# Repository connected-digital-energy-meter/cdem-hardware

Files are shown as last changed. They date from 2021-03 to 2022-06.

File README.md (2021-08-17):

# Connected Digital Energy Meter - Hardware

TODO

## Gerber and BOM

Checkout following guides:

* [How to generate Gerber and Drill files in KiCad 5](https://support.jlcpcb.com/article/149-how-to-generate-gerber-and-drill-files-in-kicad)
* [How to generate the BOM and Centroid file from KiCAD](https://support.jlcpcb.com/article/84-how-to-generate-the-bom-and-centroid-file-from-kicad)

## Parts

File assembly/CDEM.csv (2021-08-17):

Comment | Designator | Footprint | LCSC
10uF | C1,C2,C3,C6 | Capacitor_SMD:C_0805_2012Metric | C15850
100nF | C4,C7,C8 | Capacitor_SMD:C_0603_1608Metric | C14663
1uF | C5 | Capacitor_SMD:C_0603_1608Metric | C15849
4.7uF | C9 | Capacitor_SMD:C_0805_2012Metric | C1779
1N5817 | D1,D2 | Diode_SMD:D_SOD-123 | C727113
power | D3 | LED_SMD:LED_0603_1608Metric | C72041
COMM | D4 | LED_SMD:LED_0603_1608Metric | C72043
DATA | D5 | LED_SMD:LED_0603_1608Metric | C72038
USB_C_Receptacle_USB2.0 | J1 | Connector_USB:USB_C_Receptacle_HRO_TYPE-C-31-M-12 | C165948
6P6C | J2 | Connector_RJ:RJ12_Amphenol_54601 | C305981
Conn_01x03 | J4 | Connector_PinHeader_2.54mm:PinHeader_1x03_P2.54mm_Vertical | C390679
2N7002 | Q1 | Package_TO_SOT_SMD:SOT-23 | C8545
S8050 | Q2,Q3 | Package_TO_SOT_SMD:SOT-23 | C2146
10k | R1,R2,R3,R6,R8,R9,R10,R11,R12 | Resistor_SMD:R_0603_1608Metric | C25804
1M | R13 | Resistor_SMD:R_0603_1608Metric | C17514
1k | R4,R5,R7 | Resistor_SMD:R_0603_1608Metric | C21190
BTN | SW1 | Button_Switch_SMD:SW_SPST_B3U-1000P | C231329
RESET | SW2 | Button_Switch_SMD:SW_SPST_B3U-1000P | C231329
MCP1825S | U1 | Package_TO_SOT_SMD:SOT-223-3_TabPin2 | C145411
USBLC6-2SC6 | U2 | Package_TO_SOT_SMD:SOT-23-6 | C7519
CP2104 | U3 | Package_DFN_QFN:QFN-24-1EP_4x4mm_P0.5mm_EP2.6x2.6mm | C47742
ESP-12E | U4 | RF_Module:ESP-12E | C82898

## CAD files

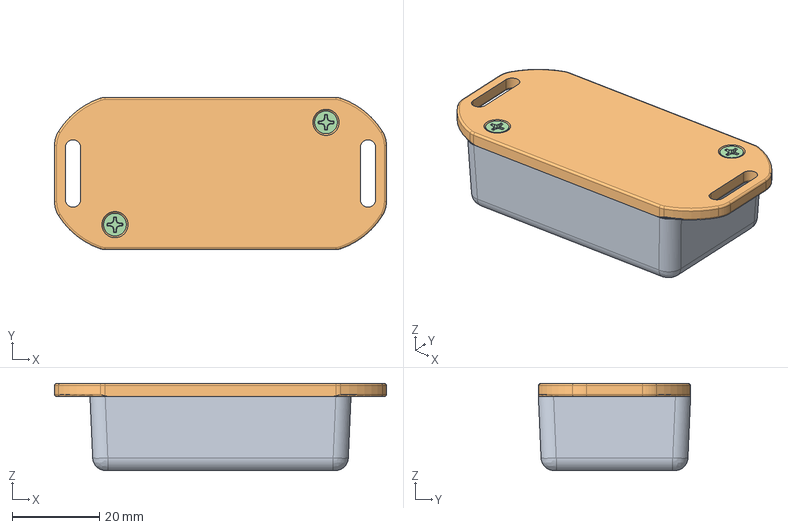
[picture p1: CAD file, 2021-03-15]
3Dmodels/1551HFL.stp
76.3 x 35.0 x 20.0 mm
1551H Box
1551H-J Flange Lid
1551H PCB

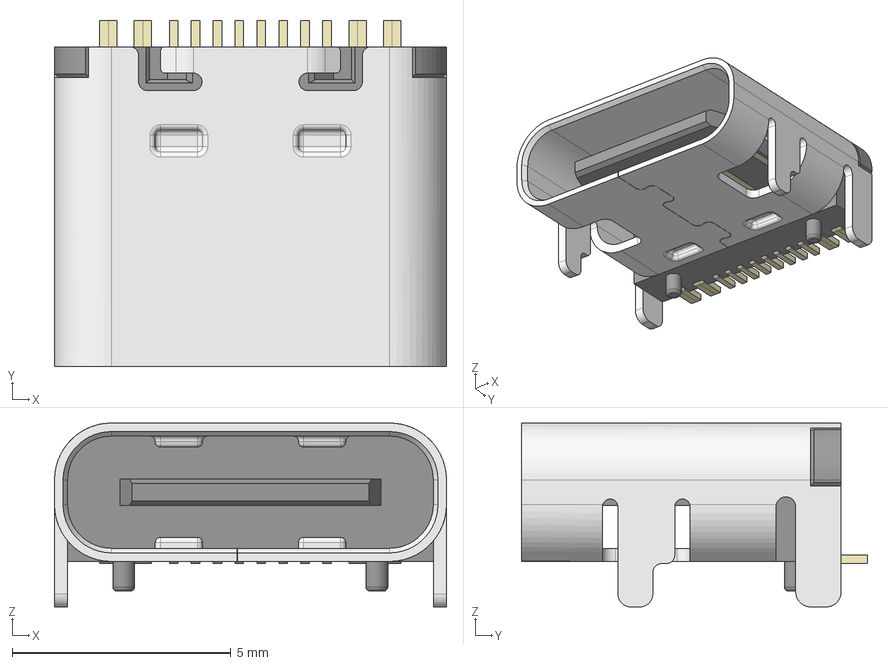
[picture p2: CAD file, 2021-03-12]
3Dmodels/HRO_TYPE-C-31-M-12.step
8.95 x 7.90 x 4.20 mm

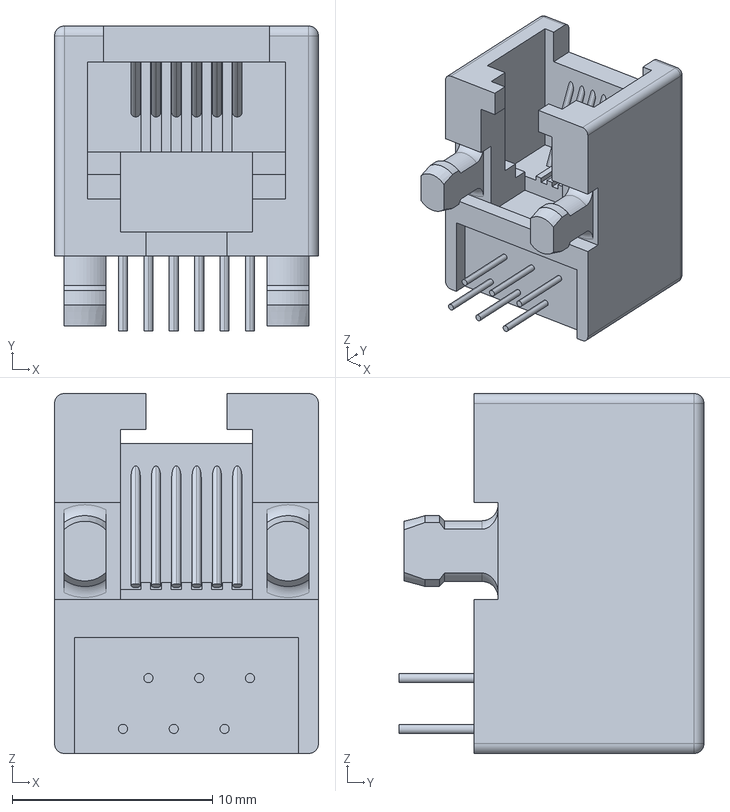
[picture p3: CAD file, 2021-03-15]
3Dmodels/54601-906WPLFc.stp
13.2 x 15.2 x 18.0 mm

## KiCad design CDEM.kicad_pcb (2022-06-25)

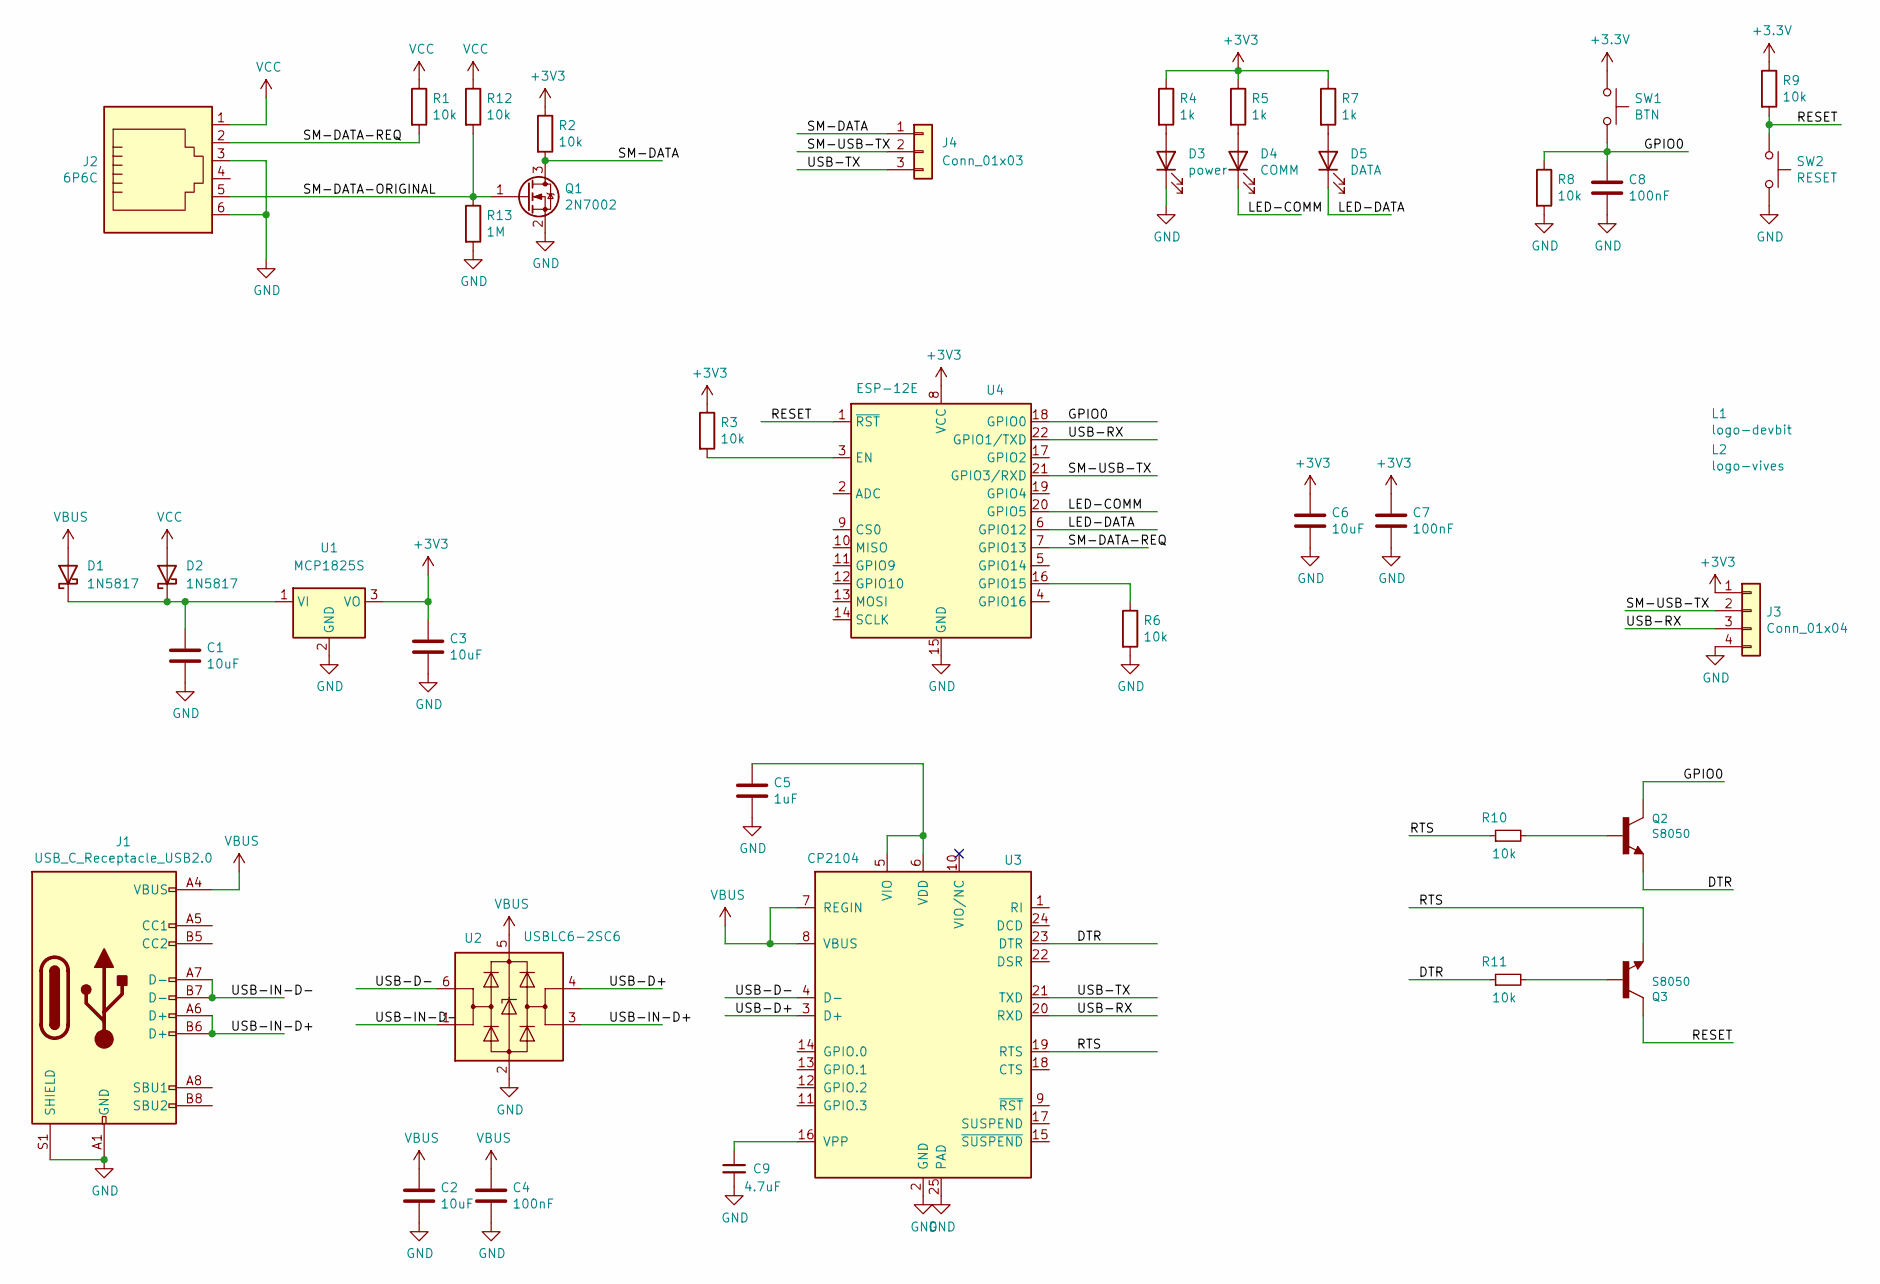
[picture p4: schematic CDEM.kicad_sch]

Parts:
C1, C2, C3, C6: 10uF; C_0805_2012Metric; LCSC C15850
C4, C7, C8: 100nF; C_0603_1608Metric; LCSC C14663
C5: 1uF; C_0603_1608Metric; LCSC C15849
C9: 4.7uF; C_0805_2012Metric; LCSC C1779
D1, D2: 1N5817; D_SOD-123; LCSC C727113
D3: power; LED_0603_1608Metric; LCSC C72041
D4: COMM; LED_0603_1608Metric; LCSC C72043
D5: DATA; LED_0603_1608Metric; LCSC C72038
J1: USB_C_Receptacle_USB2.0; USB_C_Receptacle_HRO_TYPE-C-31-M-12; LCSC C165948
J2: 6P6C; RJ12_Amphenol_54601; LCSC C305981
J3: Conn_01x04; PinHeader_1x04_P2.54mm_Vertical
J4: Conn_01x03; PinHeader_1x03_P2.54mm_Vertical; LCSC C390679
L1: logo-devbit; logo_devbit_8mm
L2: logo-vives; logo_vives_10mm
Q1: 2N7002; SOT-23; LCSC C8545
Q2, Q3: S8050; SOT-23; LCSC C2146
R1, R2, R3, R6, R8, R9, R10, R11, R12: 10k; R_0603_1608Metric; LCSC C25804
R4, R5, R7: 1k; R_0603_1608Metric; LCSC C21190
R13: 1M; R_0603_1608Metric; LCSC C17514
SW1: BTN; SW_SPST_B3U-1000P; LCSC C231329
SW2: RESET; SW_SPST_B3U-1000P; LCSC C231329
U1: MCP1825S; SOT-223-3_TabPin2; LCSC C145411
U2: USBLC6-2SC6; SOT-23-6; LCSC C7519
U3: CP2104; QFN-24-1EP_4x4mm_P0.5mm_EP2.6x2.6mm; LCSC C47742
U4: ESP-12E; LCSC C82898

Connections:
/DTR: Q2.2 (E), R11.1, U3.23 (DTR)
/GPIO0: C8.1, Q2.3 (C), R8.1, SW1.2, U4.18 (GPIO0)
/LED-COMM: D4.1 (K), U4.20 (GPIO5)
/LED-DATA: D5.1 (K), U4.6 (GPIO12)
/RESET: Q3.3 (C), R9.2, SW2.1, U4.1 (~RST)
/RTS: Q3.2 (E), R10.1, U3.19 (RTS)
/SM-DATA: J4.1, Q1.3 (D), R2.2
/SM-DATA-ORIGINAL: J2.5, Q1.1 (G), R12.2, R13.1
/SM-DATA-REQ: J2.2, R1.2, U4.7 (GPIO13)
/SM-USB-TX: J3.2, J4.2, U4.21 (GPIO3/RXD)
/USB-D+: U2.4 (I/O2), U3.3 (D+)
/USB-D-: U2.6 (I/O1), U3.4 (D-)
/USB-IN-D+: J1.A6 (D+), J1.B6 (D+), U2.3 (I/O2)
/USB-IN-D-: J1.A7 (D-), J1.B7 (D-), U2.1 (I/O1)
/USB-RX: J3.3, U3.20 (RXD), U4.22 (GPIO1/TXD)
/USB-TX: J4.3, U3.21 (TXD)
GND: C1.2, C2.2, C3.2, C4.2, C5.2, C6.2, C7.2, C8.2, C9.2, D3.1 (K), J1.A1 (GND), J1.A12 (GND), J1.B1 (GND), J1.B12 (GND), J1.S1 (SHIELD), J2.3, J2.6, J3.4, Q1.2 (S), R6.2, R8.2, R13.2, SW2.2, U1.2 (GND), U2.2 (GND), U3.2 (GND), U3.25 (PAD), U4.15 (GND)
unnamed: C1.1, D1.1 (K), D2.1 (K), U1.1 (VI)
unnamed: C5.1, U3.5 (VIO), U3.6 (VDD)
unnamed: C9.1, U3.16 (VPP)
unnamed: D3.2 (A), R4.2
unnamed: D4.2 (A), R5.2
unnamed: D5.2 (A), R7.2
unnamed: Q2.1 (B), R10.2
unnamed: Q3.1 (B), R11.2
unnamed: R3.2, U4.3 (EN)
unnamed: R6.1, U4.16 (GPIO15)
VBUS: C2.1, C4.1, D1.2 (A), J1.A4 (VBUS), J1.A9 (VBUS), J1.B4 (VBUS), J1.B9 (VBUS), U2.5 (VBUS), U3.7 (REGIN), U3.8 (VBUS)
VCC: D2.2 (A), J2.1, R1.1, R12.1

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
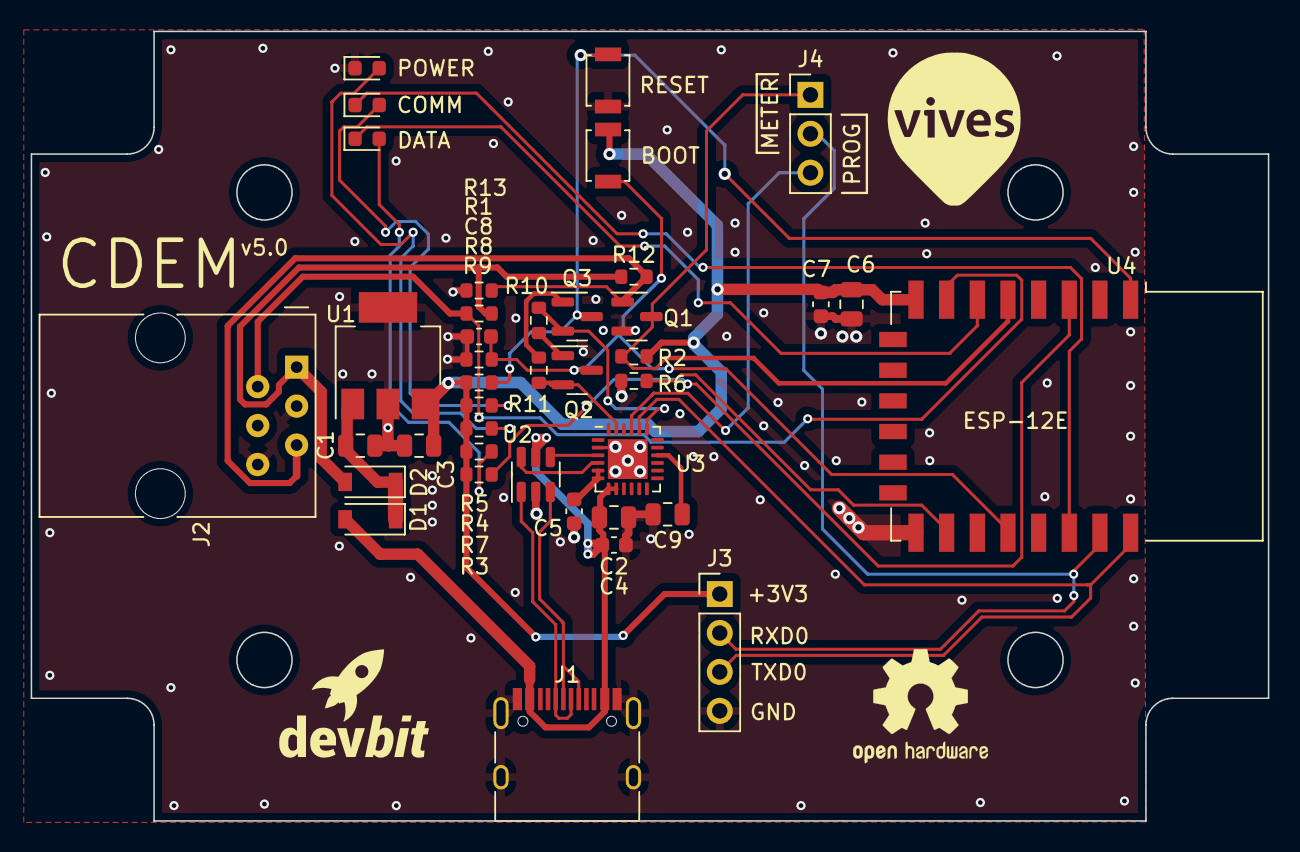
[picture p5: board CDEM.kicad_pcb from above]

Board: 2 copper layers, 80.7 x 51.5 mm, 42 parts (0 on the bottom side), 30 nets.

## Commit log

2021-03-15 finisched routing
    [1551HFL.stp, 54601-906WPLFc.stp, CDEM.kicad_pcb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]
2021-03-15 finisching up the board
    [CDEM.kicad_pcb, CDEM.kicad_sch]
2021-03-15 add v4.0 laber on pcb
    [CDEM.kicad_pcb]
2021-03-16 generate bom and pos files
    [CDEM-B_Cu.gbr, CDEM-B_Mask.gbr, CDEM-B_Paste.gbr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]
2021-03-16 final version v4.0
    [CDEM-B_Cu.gbr, CDEM-B_Mask.gbr, CDEM-B_Paste.gbr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]
2021-06-25 Replace LDO and diodes with better alternatives. Also add programming jumper
    [CDEM.kicad_pcb, CDEM.kicad_sch]
2021-08-17 Move prog jumper a bit
    [CDEM.kicad_pcb]
2021-08-17 Finalize v5.0 and generate gerber and bom files
    [CDEM-B_Cu.gbr, CDEM-B_Mask.gbr, CDEM-B_Paste.gbr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]
2021-09-24 Update orientation of components
    [CDEM-top-pos.csv]
2022-06-25 fix unconnected trace to boot button
    [CDEM.kicad_pcb]
